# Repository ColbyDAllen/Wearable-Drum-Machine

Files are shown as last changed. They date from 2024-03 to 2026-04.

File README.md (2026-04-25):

# Wearable Drum Machine 

12/15/2024 |

This project is mostly complete. Until I can find a more suitable input/sensory solution, please consider this work on hiatus.

Further information can be found at www.colbydanielallen.com.

4/15/2024 |

This project is still in development. 

On the hardware side, I'm focused on creating more reliable FSR finger sensors.
Weather resistant (magentic charger?) enclosure design is backlogged.

On the circuitry side, I'm designing a custom PCB that incorporates power management, sensor/usb/programmig ports, and an embedded speaker module. 

On the software side there's a number of backlogged tasks. I want to fine-tune / build-out the MIDI looping functionality and create a richer way to sequence these patterns. Variable tempo control in standalone operation (via rotary encoder) is also backlogged.

----

04/01/2024 | Regarding software/code:
Until I've split these up into functional sections, the .ino sketches will build on each other in the following order:
1) FSR Input
2) SMF File Storage
3) MIDI Looper

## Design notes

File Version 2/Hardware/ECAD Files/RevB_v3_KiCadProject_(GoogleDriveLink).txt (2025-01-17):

Link to KiCad Project (A bit messy) via Google Drive:

https://drive.google.com/file/d/1cKTnNXydSSYptlRRjlfMmF5JMNGvhg2D/view?usp=sharing

If missing and you would like to download for personal use, feel free to contact me at:

colbyallen939@u.boisestate.edu

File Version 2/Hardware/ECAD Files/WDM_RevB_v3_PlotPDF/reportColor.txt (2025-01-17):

Plotted to 'C:\Users\Colby\Desktop\Programs\KiCad\WDM_RevB_v3\WDM_RevB_v3\WDM_RevB_v3_PlotPDF\WDM_RevB_v3-Edge_Cuts.pdf'.
Plotted to 'C:\Users\Colby\Desktop\Programs\KiCad\WDM_RevB_v3\WDM_RevB_v3\WDM_RevB_v3_PlotPDF\WDM_RevB_v3-F_Fab.pdf'.
Plotted to 'C:\Users\Colby\Desktop\Programs\KiCad\WDM_RevB_v3\WDM_RevB_v3\WDM_RevB_v3_PlotPDF\WDM_RevB_v3-B_Fab.pdf'.
Info: Done.

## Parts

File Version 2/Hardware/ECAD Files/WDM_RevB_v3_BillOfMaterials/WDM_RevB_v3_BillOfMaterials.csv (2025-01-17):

Id | Designator | Footprint | Quantity | Designation | Supplier and ref
1 | U4 | SO3016_SPA-M | 1 | S25FL512SAGMFIR13_512MBIT
2 | R20,R24,R15,R25,R26,R14,R27,R16,R22,R28,R17,R21,R37,R29,R19,R23,R30 | RES_10K_R0805 | 17 | 10K
3 | J2 | Teensy4.1_Colby(Footprint) | 1 | T4.1
4 | R33,R36,R39,R40,R34,R32,R35,R31,R43 | RES_2.2K_0805 | 9 | 2.2K
5 | U5 | AP7313-18SAG-7 | 1 | AP7313-18SAG-7
6 | C7,C8 | C_100nF_0805 | 2 | 100 nF
7 | TP2 | TestPoint_PAD.03X.05 | 1 | VPCC(TP)
8 | D2 | CHIPLED_0805_NOOUTLINE | 1 | ORANGE
9 | JP1,JP2,JP3 | SolderJumper-2_P1.3mm_Bridged_Pad1.0x1.5mm | 3 | JUMPER-SMT_2_NC_TRACE_SILK
10 | L2 | IND_2012_TDK-L | 1 | 600 OHM, MPZ2012S601AT000
11 | C11,C18,C10,C2,C19 | C_0.1uF_0805_10MGAP | 5 | 0.1 uF
12 | C17,C12,C9,C4,C20 | C_2.2uF_0805-NO | 5 | 2.2 uF
13 | D3,D6 | CHIPLED_0805_NOOUTLINE | 2 | GREEN
14 | SPKR1 | AdafruitStemmaSpeaker_3923 | 1 | ~
15 | EN_1 | XDCR_PEC11R-4215F-S0024 | 1 | PEC11R-4215F-S0024
16 | SW_4,SW_8,SW_5,SW_7,SW_9,SW_3,SW_2,SW_6,SW_1 | PushButton_KMR211_G_LFS_CNK | 9 | KMR211GLFS
17 | C16,C1,C6,C3 | C_10uF_0805-NO | 4 | 10 uF
18 | U3 | W25Q128JVSIQ | 1 | W25Q128JVSIQ
19 | T1 | MMUN2133LT1G_SC59-BEC | 1 | MMUN2133LT1G
20 | J4,J5 | 1X01_BatteryTerminal_HandSolder | 2 | ~
21 | U6 | QFN50P500X500X90-33N | 1 | SGTL5000XNBA3R2
22 | D4,D8,D10 | CHIPLED_0805_NOOUTLINE | 3 | BLUE
23 | J14 | 53398-0271 | 1 | CONN HEADER SMD R/A 2POS 1.25MM
24 | R13 | RES_100K_0805 | 1 | 50K
25 | D9,D7 | CHIPLED_0805_NOOUTLINE | 2 | YELLOW
26 | U7 | MSOP8_0.65MM | 1 | PAM8302AASCR
27 | TP7 | TestPoint_PAD.03X.05 | 1 | +3V3
28 | TP6 | TestPoint_PAD.03X.05 | 1 | SIG(TP)
29 | R41,R38,R42 | RES_100R_R0805 | 3 | 100R
30 | TP5 | TestPoint_PAD.03X.05 | 1 | GND(TP)
31 | D5,D1 | CHIPLED_0805_NOOUTLINE | 2 | RED
32 | J15 | CUI_SJ-3541AS-SMT-TR-67 | 1 | SJ-3541AS-SMT-TR-67
33 | R1,R4 | RES_1.87M_0805 | 2 | 1.87M
34 | C5 | C_100uF_MLCC_C1210 | 1 | 100 uF
35 | J11,J6,J3,J7 | CUI_SJ-3542AS-SMT-TR-67 | 4 | SJ-3542AS-SMT-TR-67
36 | C13 | C_0.15uF_0805 | 1 | 0.15 uF
37 | MIC1 | 1X02_TH_ | 1 | POM-5046P-C3310-R
38 | R2 | RES_340K_0805 | 1 | 340K
39 | R11 | RES_100K_0805 | 1 | 100K
40 | R8,R7,R9,R6 | RES_1K_0805 | 4 | 1K
41 | R12 | RES_1K_0805 | 1 | 3.3K
42 | U1 | TPS61090RSAR_PVQFN-16 | 1 | TPS61090RSAR
43 | C15,C14 | C_1uF_0805 | 2 | 1 uF
44 | R18 | Thermo_15K_0805-NO | 1 | 15K
45 | VR1 | TRIMPOT_BOURNS_TC42_2mm_SMD | 1 | 10K_TC42_Trimpot
46 | L1 | VLS5045EX330M | 1 | 6.8uH, VLS5045EX-6R8M-H
47 | R3,R5 | RES_200K_0805 | 2 | 200K
48 | U2 | MCP73871_QFN20_4MM | 1 | MCP73871
49 | R10 | RES_270K_0805 | 1 | 270K
50 | SW1 | JS202011JAQN | 1 | JS202011JAQN Slide Switch DPDT Surface Mount, Right Angle
51 | TP4 | TestPoint_PAD.03X.05 | 1 | +3v3(TP)

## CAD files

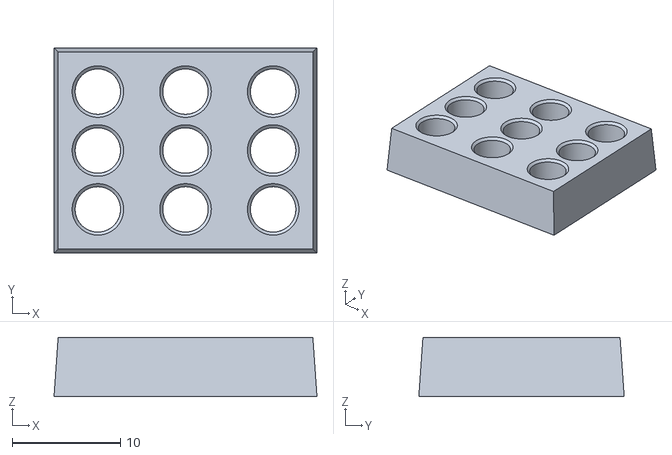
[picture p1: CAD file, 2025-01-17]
Version 2/Hardware/MCAD Files/TestUpload_(Don'tUseUnlessItHelps)/RevB_V3_Assembly - ButtonCasing_WDM(RevB)_Redo4.2-2.STL
24.3 x 19.0 x 5.48

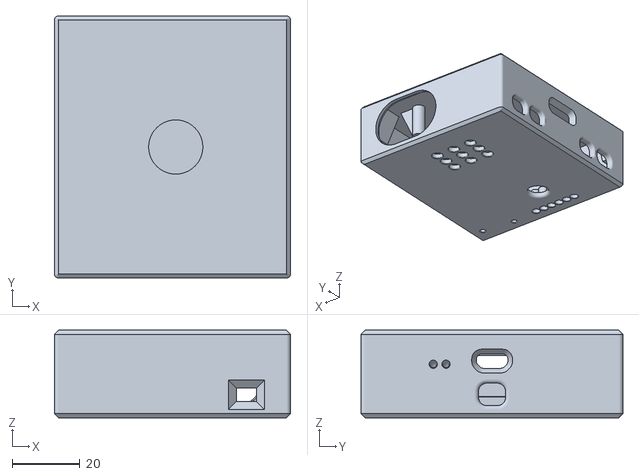
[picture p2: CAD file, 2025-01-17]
Version 2/Hardware/MCAD Files/TestUpload_(Don'tUseUnlessItHelps)/RevB_V3_Assembly - Enclosure_Redo4.3(Backup)-1.STL
69.8 x 77.4 x 25.8

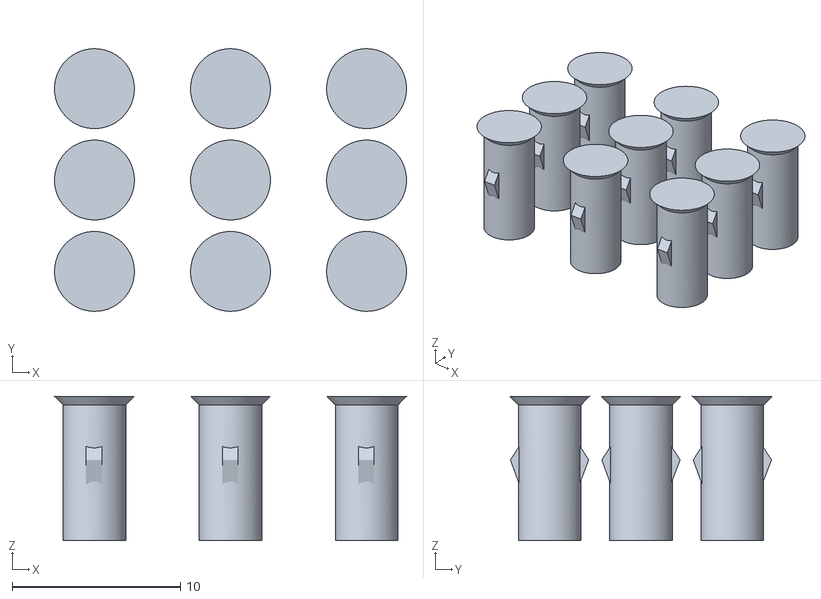
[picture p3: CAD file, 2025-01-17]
Version 2/Hardware/MCAD Files/TestUpload_(Don'tUseUnlessItHelps)/RevB_V3_Assembly - ButtonCaps_Redo4.2-1.STL
20.9 x 15.6 x 8.58

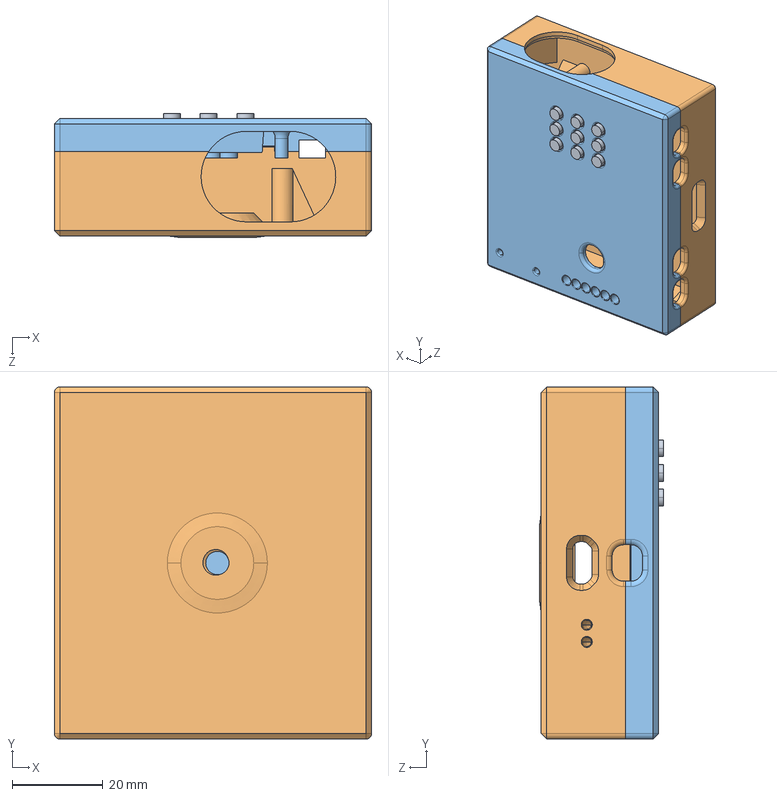
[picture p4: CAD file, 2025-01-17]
Version 2/Hardware/MCAD Files/RevB_V3_Assembly.STEP
69.8 x 77.4 x 27.3 mm

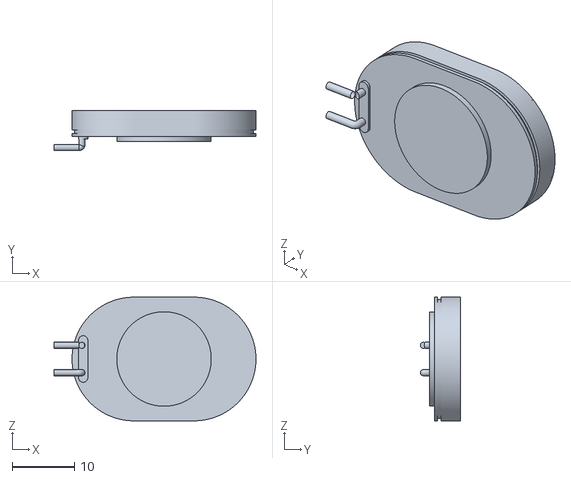
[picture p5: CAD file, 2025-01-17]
Version 2/Hardware/MCAD Files/TestUpload_(Don'tUseUnlessItHelps)/RevB_V3_Assembly - OvalSpeaker_Redo4.2-1.STL
32.5 x 6.50 x 19.9

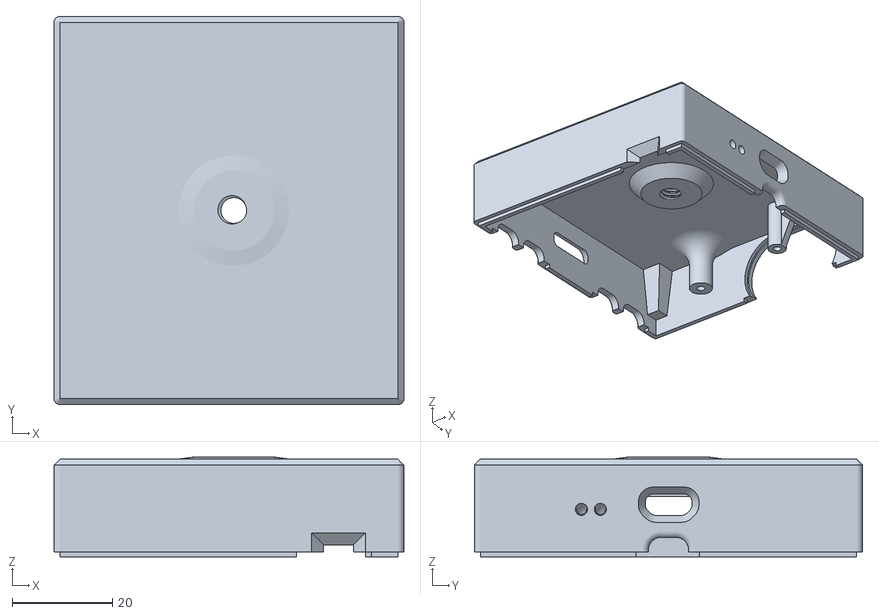
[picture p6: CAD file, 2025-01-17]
Version 2/Hardware/MCAD Files/RevB_V3_BottomEnclosure.STL
69.8 x 77.4 x 19.9

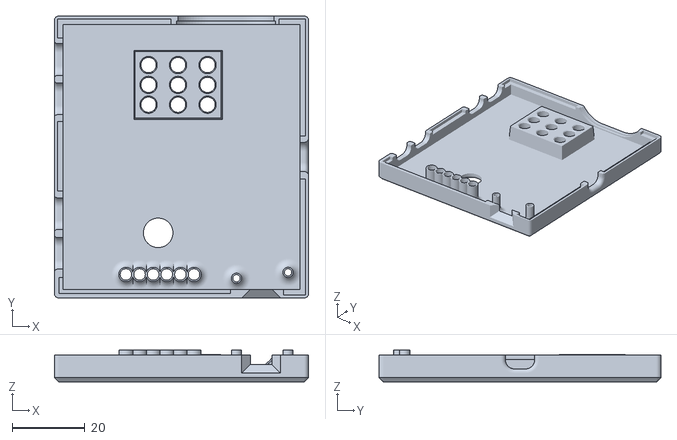
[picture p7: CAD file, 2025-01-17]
Version 2/Hardware/MCAD Files/RevB_V3_TopEnclosure.STL
69.8 x 77.4 x 8.74

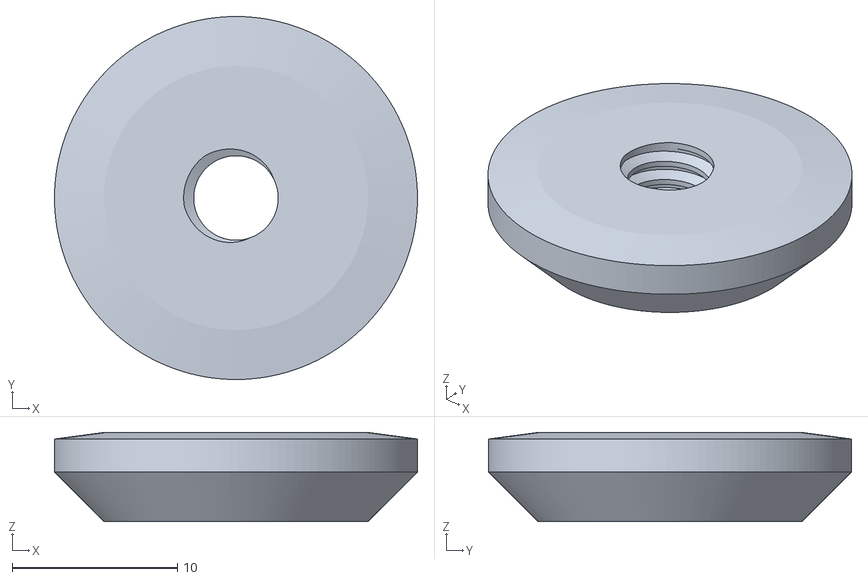
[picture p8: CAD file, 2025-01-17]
Version 2/Hardware/MCAD Files/TestUpload_(Don'tUseUnlessItHelps)/RevB_V3_Assembly - Bolt_Female_WDM(RevB)_Redo4.2-1.STL
22.0 x 22.0 x 5.40

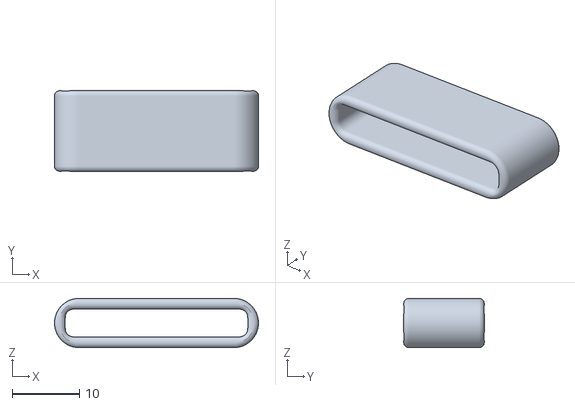
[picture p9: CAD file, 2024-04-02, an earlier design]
Version 1/Hardware/Fusion360/STLs/strap-loop_V1.1.stl
30.4 x 12.0 x 7.33

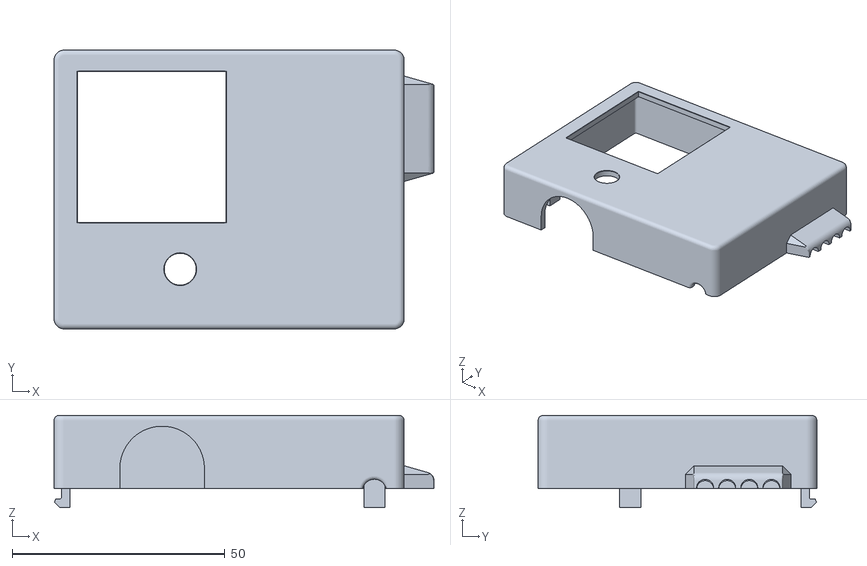
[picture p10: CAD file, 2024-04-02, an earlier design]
Version 1/Hardware/Fusion360/STLs/top-wrist_V1.1.stl
89.4 x 65.6 x 21.7

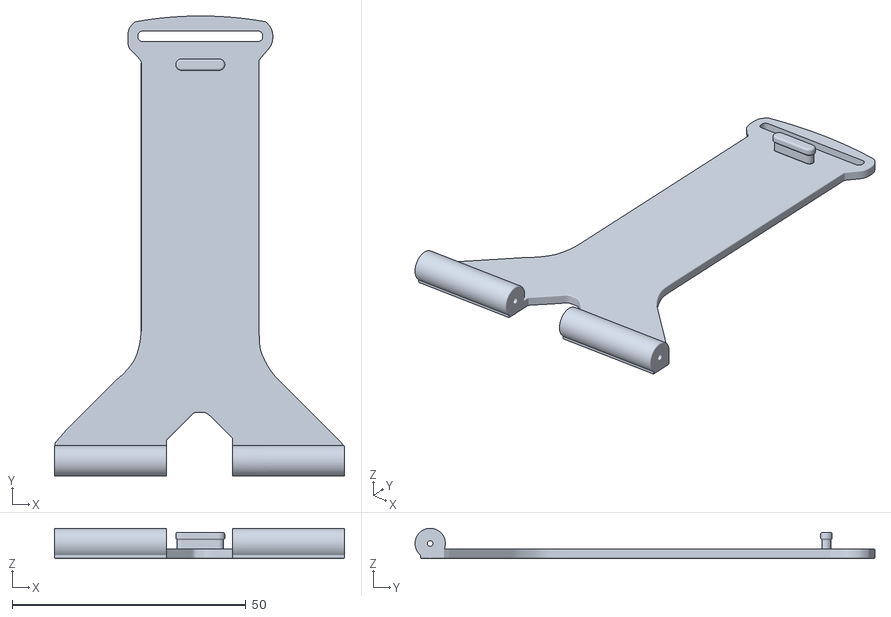
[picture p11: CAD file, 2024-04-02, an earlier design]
Version 1/Hardware/Fusion360/STLs/strap-male_V1.1.stl
62.0 x 98.3 x 6.49

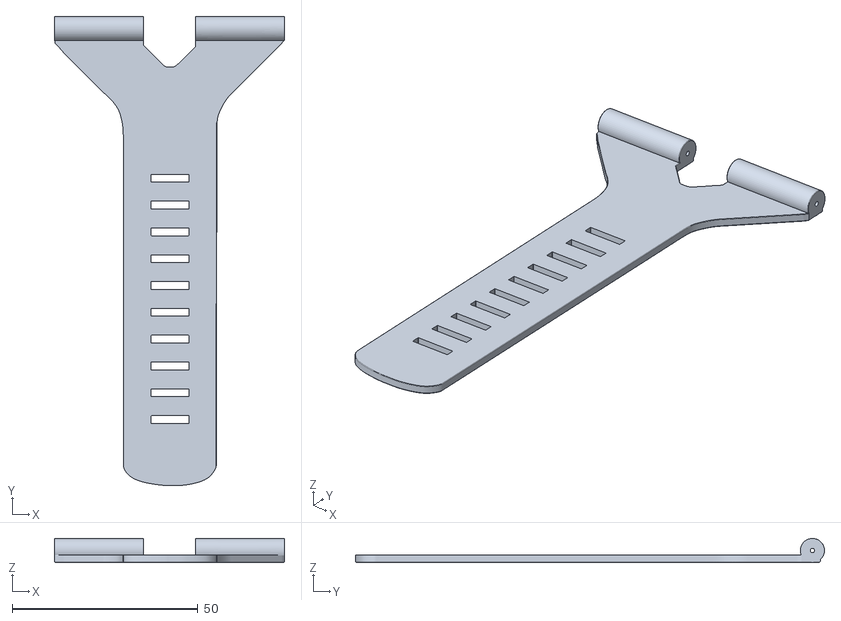
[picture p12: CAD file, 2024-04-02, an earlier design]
Version 1/Hardware/Fusion360/STLs/strap-female_V1.1.stl
62.0 x 126.3 x 6.49

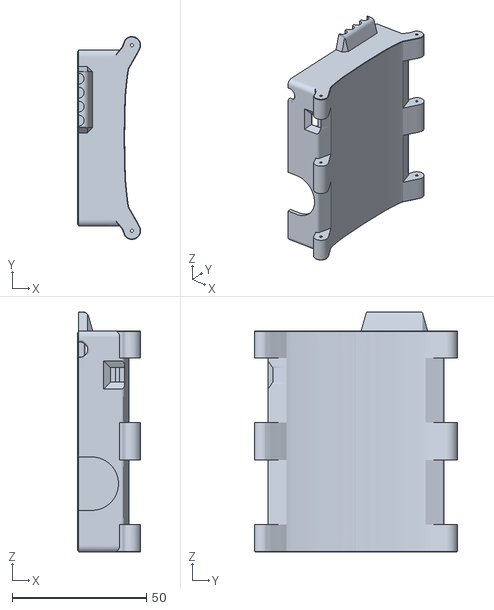
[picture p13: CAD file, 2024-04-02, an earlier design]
Version 1/Hardware/Fusion360/STLs/bottom-wrist_V1.1.stl
23.7 x 75.6 x 89.4

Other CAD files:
Version 2/Hardware/MCAD Files/RevB_V3_ButtonActuators.STL

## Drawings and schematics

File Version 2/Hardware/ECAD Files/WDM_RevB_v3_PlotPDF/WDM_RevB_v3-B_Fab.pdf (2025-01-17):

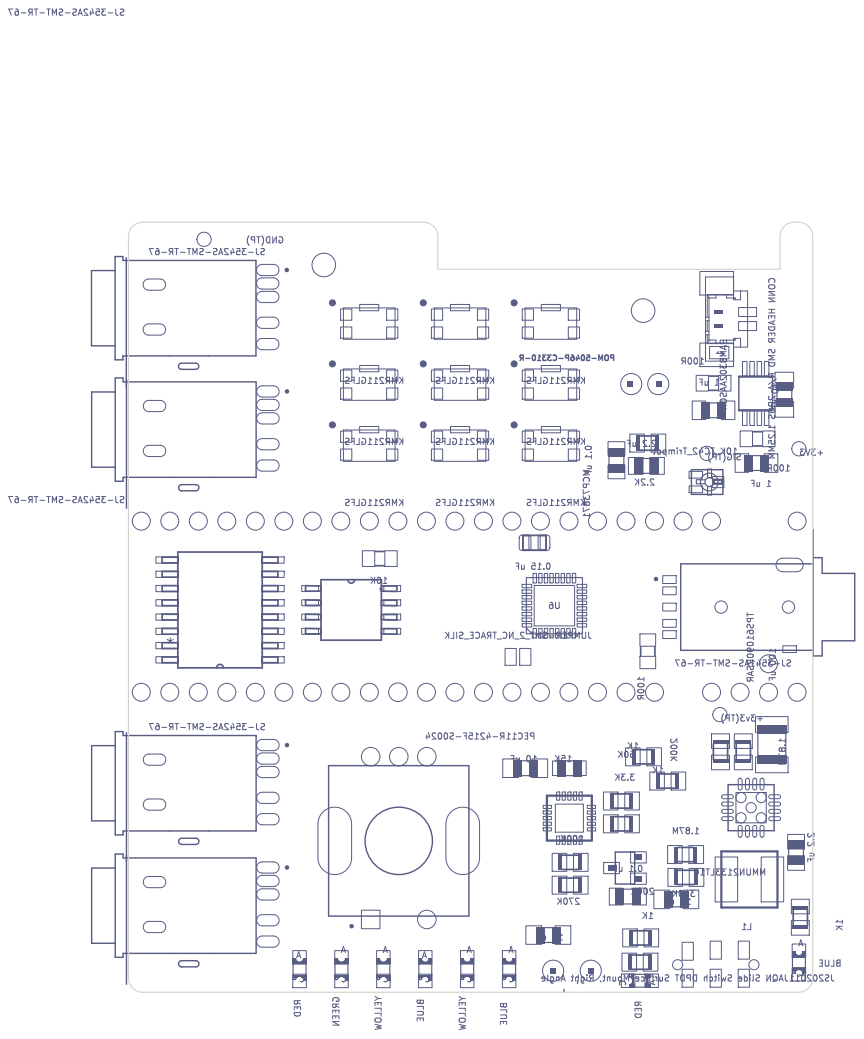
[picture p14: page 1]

SJ-3542AS-SMT-TR-67 0.1 uF

AC CONN HEADER SMD R/A 2POS 1.25MM

200K MCP73871 uF 1 SJ-3542AS-SMT-TR-67

Angle Right Mount, Surface DPDT Switch Slide JS202011JAQN 200K

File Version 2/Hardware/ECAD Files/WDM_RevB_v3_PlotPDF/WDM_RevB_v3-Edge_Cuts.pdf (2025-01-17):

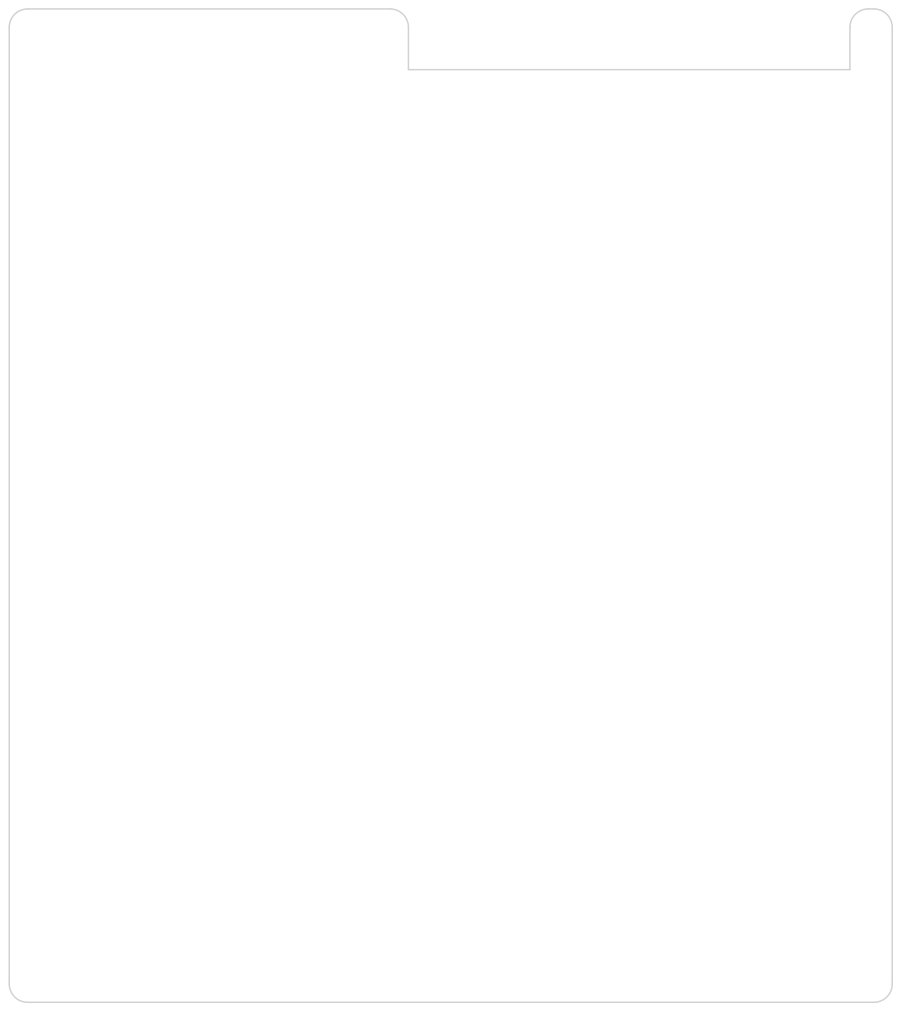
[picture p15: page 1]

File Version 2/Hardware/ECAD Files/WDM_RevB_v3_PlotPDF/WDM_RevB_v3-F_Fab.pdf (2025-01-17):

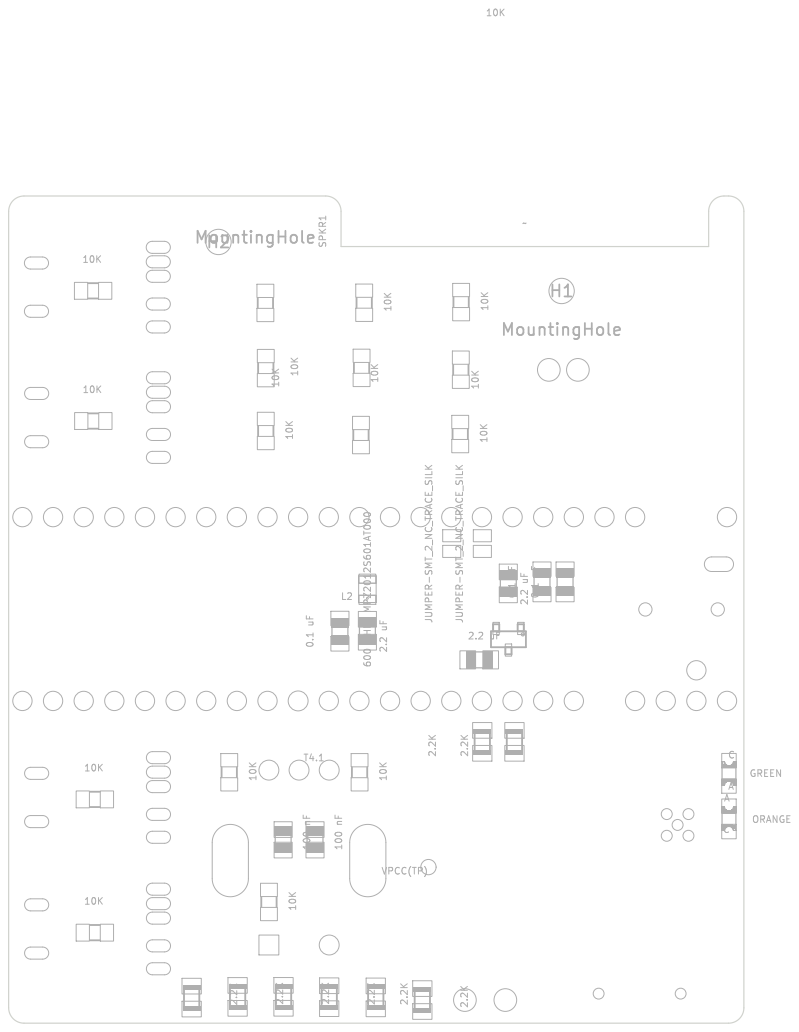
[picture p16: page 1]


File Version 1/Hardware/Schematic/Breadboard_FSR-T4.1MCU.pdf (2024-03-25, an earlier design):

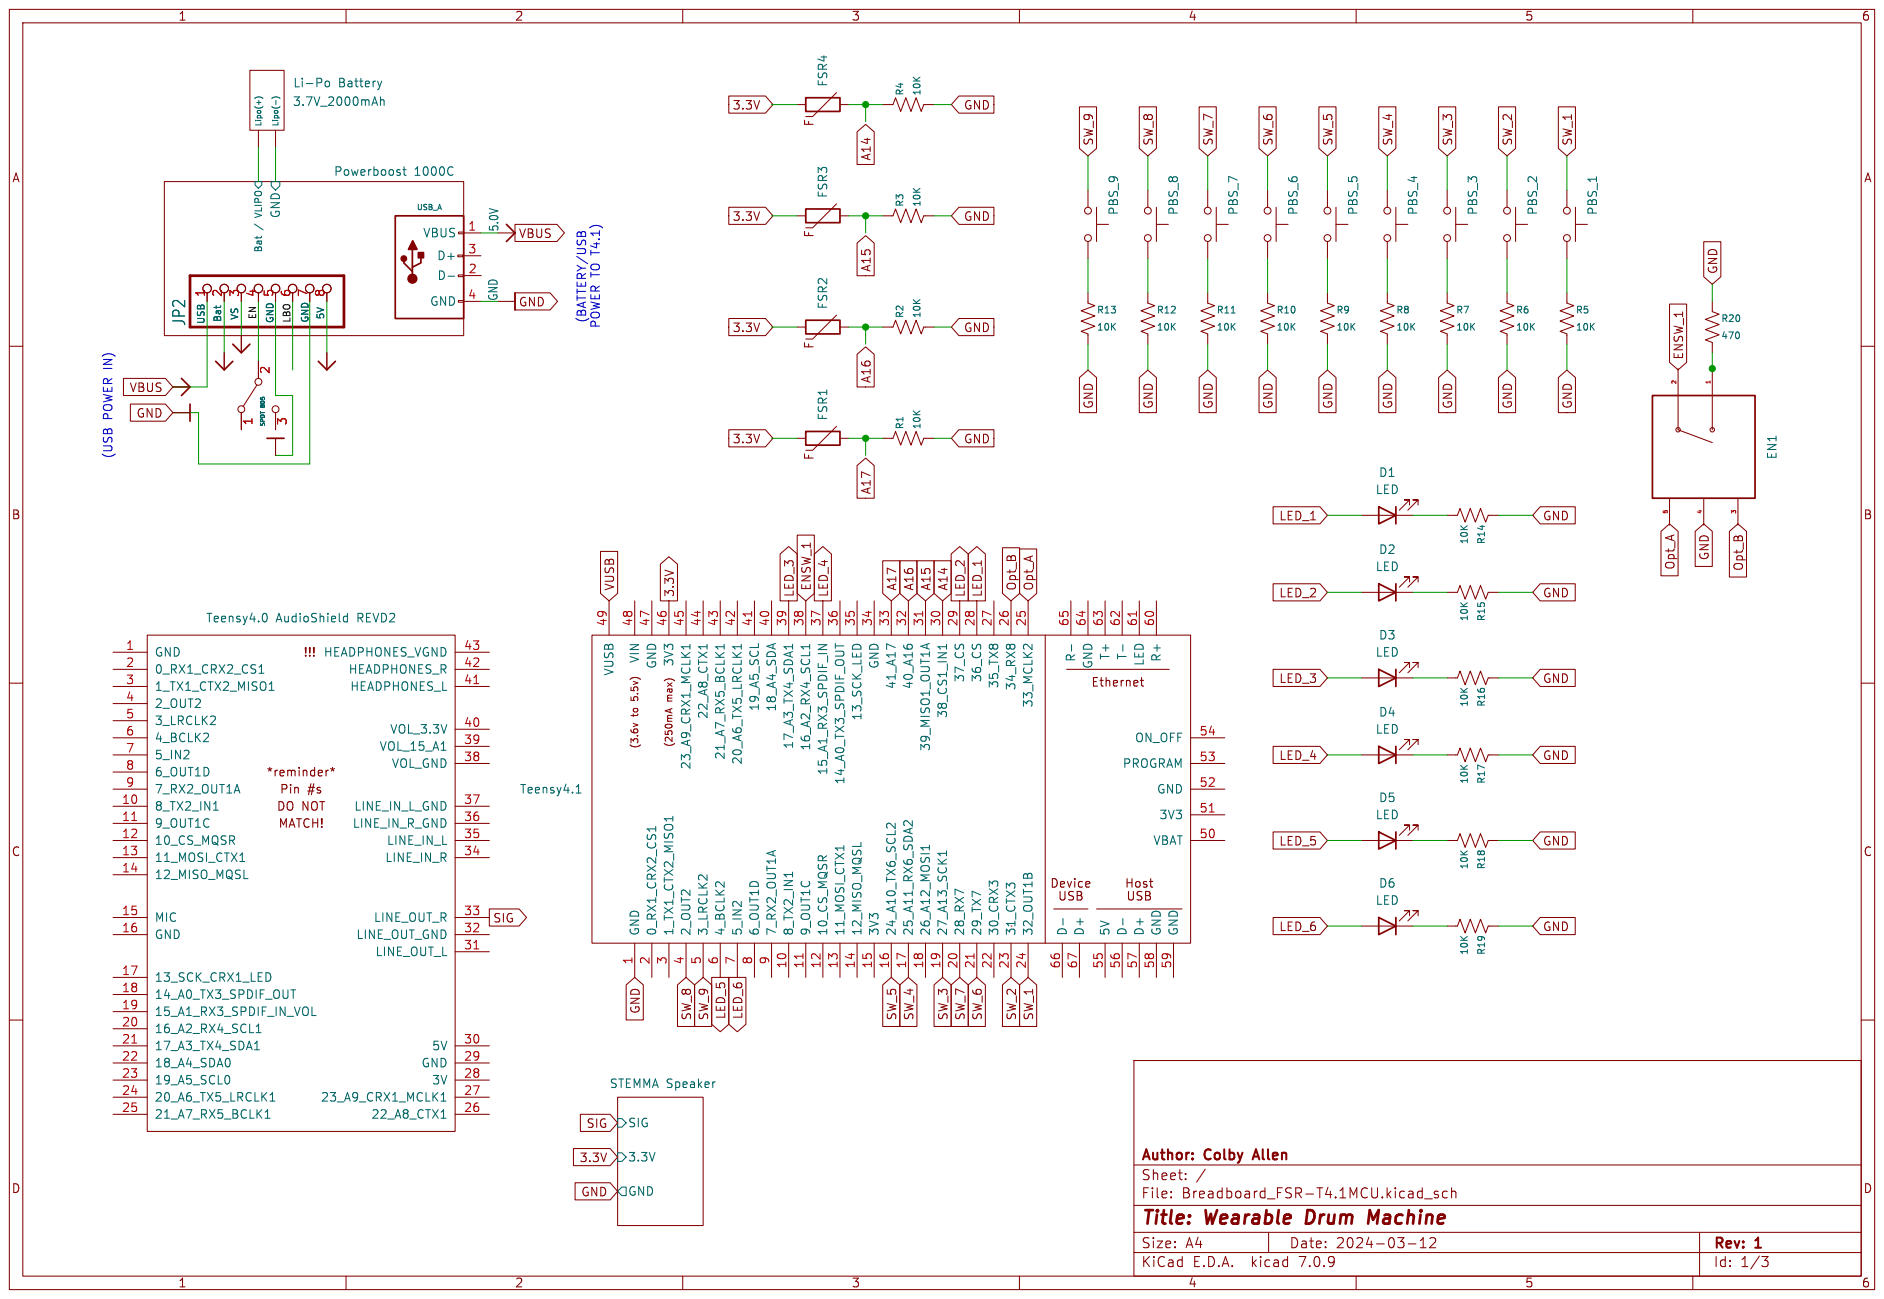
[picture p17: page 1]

2 SPDT 3 805 PBS_7 Bat GND PBS_5 USB Lipo(+) Lipo(-)3.7V_2000mAh

STEMMA Speaker Bat / VLIPO GND

8 USB Bat GND SPDT 805 1

File: Breadboard_FSR-T4.1MCU.kicad_sch Sheet: / Author: Colby Allen

Id: 1/3 Title: Wearable Drum Machine

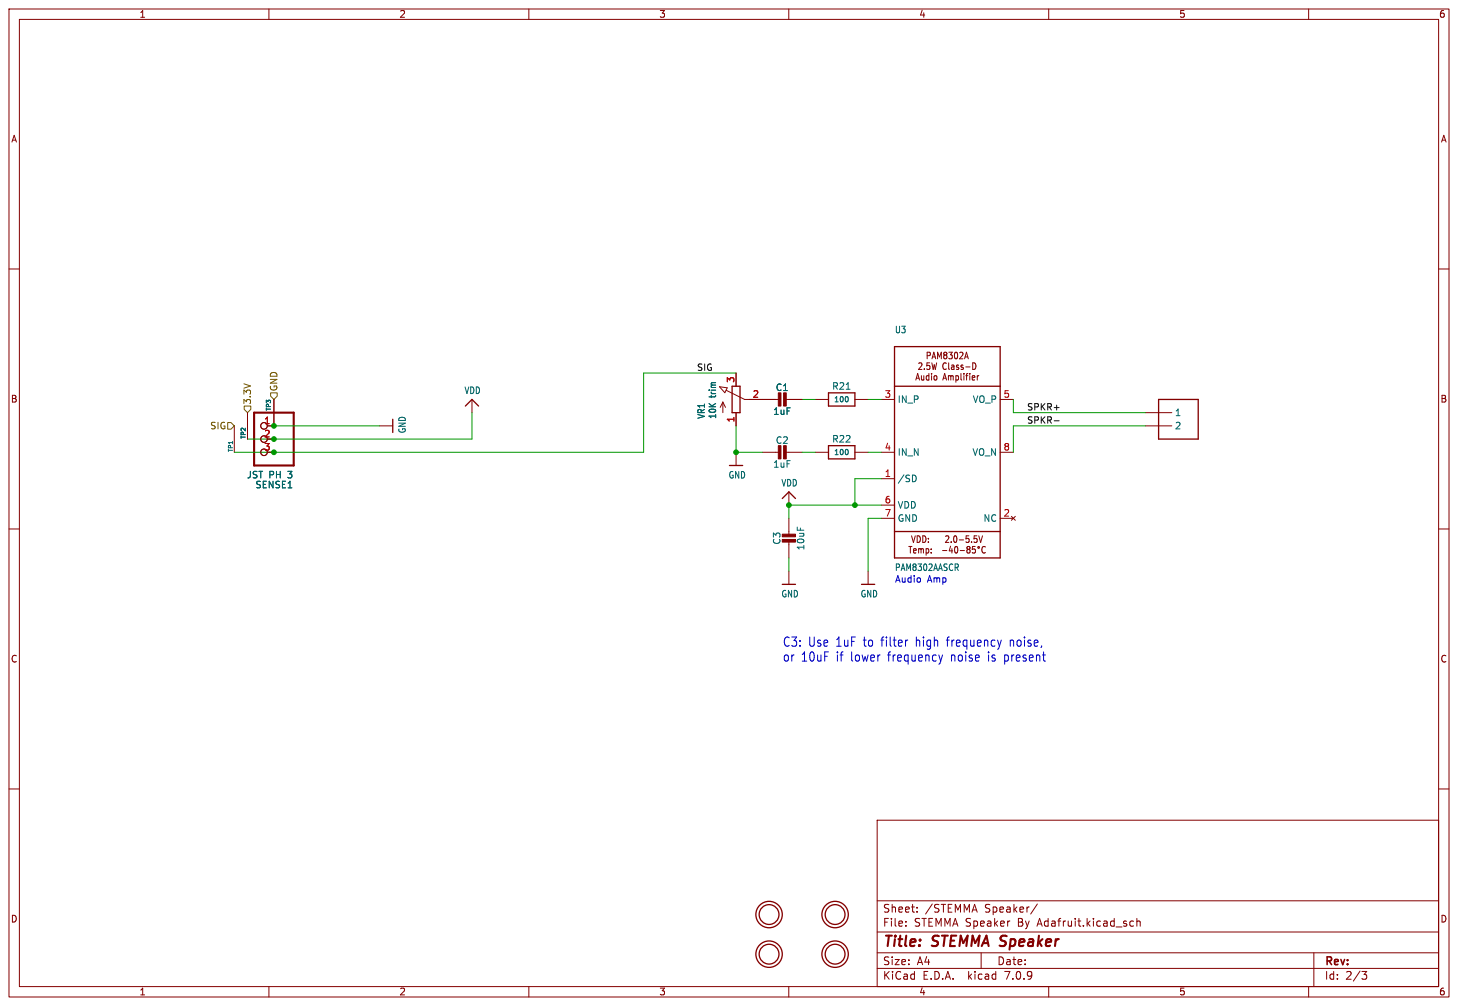
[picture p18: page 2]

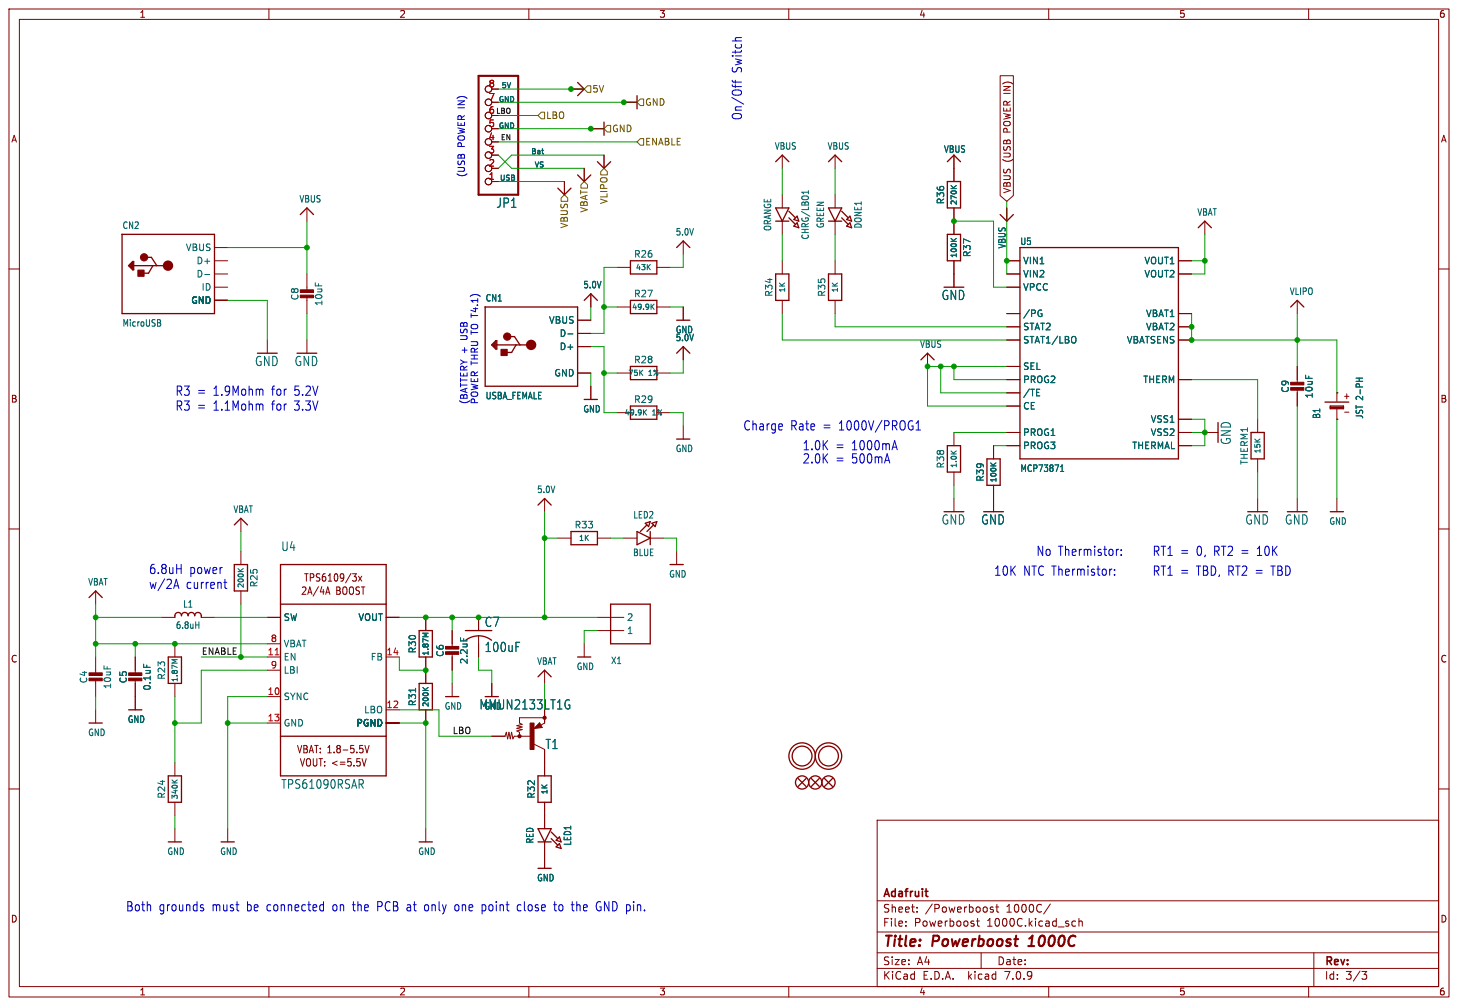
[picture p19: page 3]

10K NTC Thermistor: (BATTERY + USB POWER THRU TO T4.1)

Both grounds must be connected on the PCB at only one point close to the GND pin.

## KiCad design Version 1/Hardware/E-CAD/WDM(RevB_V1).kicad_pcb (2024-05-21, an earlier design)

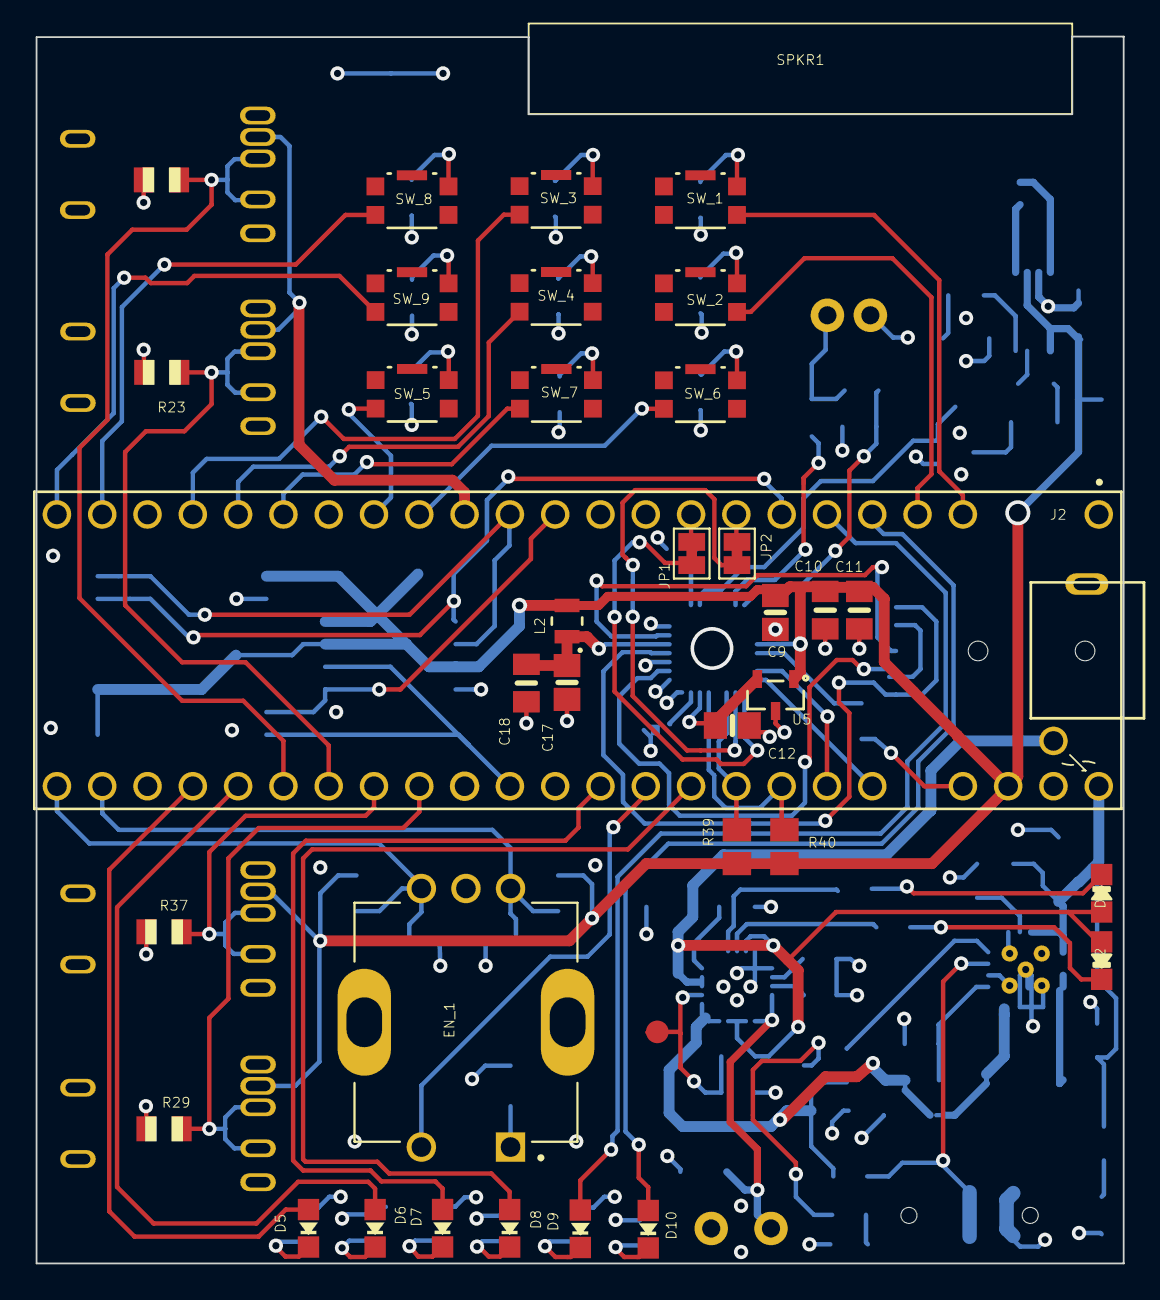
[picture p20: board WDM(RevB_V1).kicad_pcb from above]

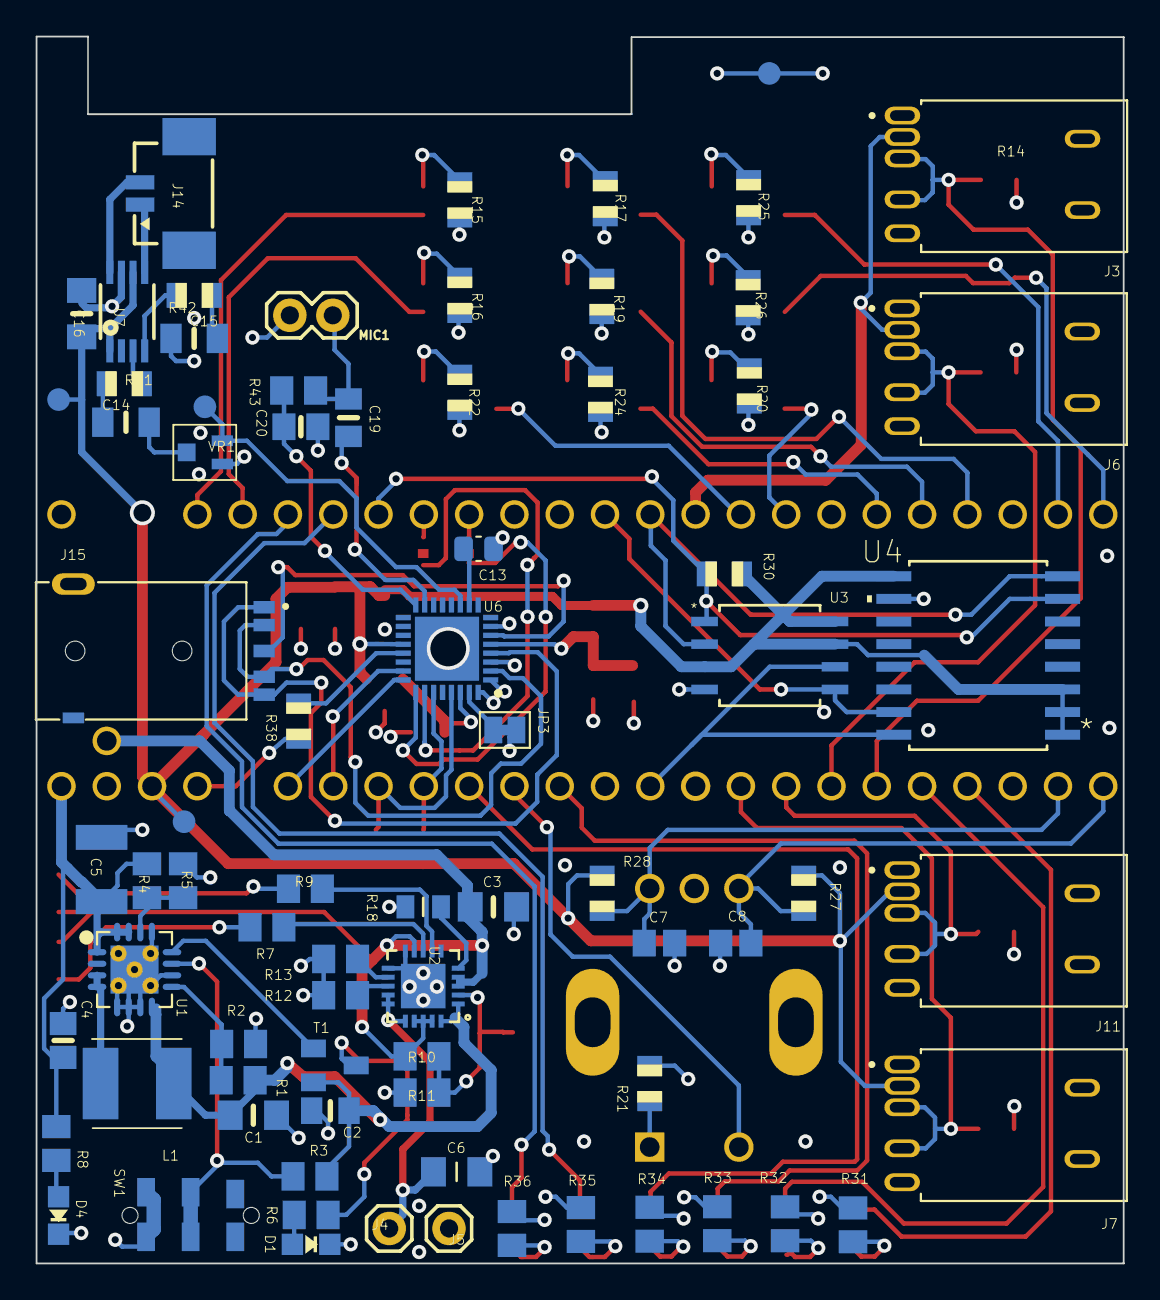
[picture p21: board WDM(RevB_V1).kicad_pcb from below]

Board: 4 copper layers, 61.0 x 68.8 mm, 114 parts (77 on the bottom side), 92 nets.

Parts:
C1, C3, C6, C16: 10 uF; C_10uF_0805-NO
C2, C10, C11, C18, C19: 0.1 uF; C_0.1uF_0805_10MGAP
C4, C9, C12, C17, C20: 2.2 uF; C_2.2uF_0805-NO
C5: 100 uF; C_100uF_MLCC_C1210
C7, C8: 100 nF; C_100nF_0805
C13: 0.15 uF; C_0.15uF_0805
C14, C15: 1 uF; C_1uF_0805
D1, D5: RED; CHIPLED_0805_NOOUTLINE
D2: ORANGE; CHIPLED_0805_NOOUTLINE
D3, D6: GREEN; CHIPLED_0805_NOOUTLINE
D4, D8, D10: BLUE; CHIPLED_0805_NOOUTLINE
D7, D9: YELLOW; CHIPLED_0805_NOOUTLINE
EN_1: PEC11R-4215F-S0024; XDCR_PEC11R-4215F-S0024
J2: T4.1; Teensy4.1_Colby(Footprint)
J3, J6, J7, J11: SJ-3542AS-SMT-TR-67; CUI_SJ-3542AS-SMT-TR-67
J4, J5: 1X01_BatteryTerminal_HandSolder
J14: CONN HEADER SMD R/A 2POS 1.25MM; 53398-0271
J15: SJ-3541AS-SMT-TR-67; CUI_SJ-3541AS-SMT-TR-67
JP1, JP2, JP3: JUMPER-SMT_2_NC_TRACE_SILK; SolderJumper-2_P1.3mm_Bridged_Pad1.0x1.5mm
L1: 6.8uH, VLS5045EX-6R8M-H; VLS5045EX330M
L2: 600 OHM, MPZ2012S601AT000; IND_2012_TDK-L
MIC1: POM-5046P-C3310-R; 1X02_TH_
R1, R4: 1.87M; RES_1.87M_0805
R2: 340K; RES_340K_0805
R3, R5: 200K; RES_200K_0805
R6, R7, R8, R9, R12: 1K; RES_1K_0805
R10: 270K; RES_270K_0805
R11, R13: 100K; RES_100K_0805
R14, R15, R16, R17, R19, R20, R21, R22, R23, R24, R25, R26, R27, R28, R29, R30, R37: 10K; RES_10K_R0805
R18: 15K; Thermo_15K_0805-NO
R31, R32, R33, R34, R35, R36, R39, R40, R43: 2.2K; RES_2.2K_0805
R38, R41, R42: 100R; RES_100R_R0805
SPKR1: AdafruitStemmaSpeaker_3923
SW1: JS202011JAQN Slide Switch DPDT Surface Mount, Rig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; JS202011JAQN
SW_1, SW_2, SW_3, SW_4, SW_5, SW_6, SW_7, SW_8, SW_9: KMR211GLFS; PushButton_KMR211_G_LFS_CNK
T1: MMUN2133LT1G; MMUN2133LT1G_SC59-BEC
TP2: VPCC(TP); TestPoint_PAD.03X.05
TP4: +3v3(TP); TestPoint_PAD.03X.05
TP5: GND(TP); TestPoint_PAD.03X.05
TP6: SIG(TP); TestPoint_PAD.03X.05
TP7: +3V3; TestPoint_PAD.03X.05
U1: TPS61090RSAR; TPS61090RSAR_PVQFN-16
U2: MCP73871; MCP73871_QFN20_4MM
U3: W25Q128JVSIQ
U4: S25FL512SAGMFIR13_512MBIT; SO3016_SPA-M
U5: AP7313-18SAG-7
U6: SGTL5000XNBA3R2; QFN50P500X500X90-33N
U7: PAM8302AASCR; MSOP8_0.65MM
VR1: 10K_TC42_Trimpot; TRIMPOT_BOURNS_TC42_2mm_SMD

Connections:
+1V8: C12.1, U5.2 (OUT), U6.30 (VDDD)
+3V3: C9.1, C10.1, C11.1, C16.1, J2.T3.3V (3.3V), J3.3, J6.3, J7.3, J11.3, L2.2, R27.1, R28.1, R30.2, R39.2, R40.2, TP4.P$1 (1), TP7.P$1 (1), U3.3 (~WP(IO2)), U3.7 (~HOLD(IO3)), U3.8 (VCC), U4.1 (~HOLD/IO3), U4.2 (VCC), U4.3 (~RESET/RFU), U4.9 (~WP/IO2), U5.1 (IN), U6.20 (VDDIO), U7.1 (/SD), U7.6 (VDD)
+5V: C4.1, C5.1, J2.+5V (VIN), R4.1, R8.1, U1.1 (VOUT), U1.15 (VOUT), U1.16 (VOUT)
/ FSRpin_1_A14: J2.38 (38_CS1_IN1), J3.2, J3.5, R14.1
/ FSRpin_2_A15: J2.39 (39_MISO1_OUT1A), J6.2, J6.5, R23.1
/ FSRpin_3_A16: J2.40 (40_A16), J11.2, J11.5, R37.1
/ FSRpin_4_A17: J2.41 (41_A17), J7.2, J7.5, R29.1
/ECHOPin: J2.24 (24_A10_TX6_SCL2), SW_6.3
/ENABLE: R3.2, SW1.2, SW1.5, U1.11 (EN)
/LBO: T1.B, U1.12 (LBO)
/PLAYledPin: D6.A, J2.37 (37_CS)
/Pin6: J2.6 (6_OUT1D), R30.1, U3.1 (~CS), U4.7 (~CS)
/Pin7: J2.7 (7_RX2_OUT1A), JP2.1
/Pin8: J2.8 (8_TX2_IN1), JP1.1
/Pin11: J2.11 (11_MOSI_CTX1), U3.5 (DI(IO0)), U4.15 (SI/IO0)
/Pin12: J2.12 (12_MISO_MQSL), U3.2 (DO(IO1)), U4.8 (SO/IO1)
/Pin13: J2.13 (13_SCK_LED), U3.6 (CLK), U4.16 (SCK)
/Pin20: J2.20 (20_A6_TX5_LRCLK1), U6.23 (I2S_LRCLK)
/Pin21: J2.21 (21_A7_RX5_BCLK1), U6.24 (I2S_SCLK)
/Pin23: J2.23 (23_A9_CRX1_MCLK1), R38.1
/RECPin: J2.32 (32_OUT1B), SW_9.3
/SCL: J2.19 (19_A5_SCL), R40.1, U6.29 (CTRL_CLK)
/SDA: J2.18 (18_A4_SDA), R39.1, U6.27 (CTRL_DATA)
/SPKR+: J14.1, U7.5 (VO_P)
/SPKR-: J14.2, U7.8 (VO_N)
/Sig: TP6.P$1 (1), U6.11 (LINEOUT_R), VR1.3 (E)
/VDDA: C17.1, C18.1, L2.1, U6.5 (VDDA)
/VPCC(TP): R10.2, R11.1, TP2.P$1 (1), U2.P$2 (VPCC)
/clockTrigPin: J2.27 (27_A13_SCK1), SW_7.3
/optAPin: C7.2, EN_1.A, J2.34 (34_RX8), R28.2
/optBPin: C8.2, EN_1.B, J2.33 (33_MCLK2), R27.2
/pushRotaryPin: EN_1.2, J2.16 (16_A2_RX4_SCL1)
/startPin: J2.31 (31_CTX3), SW_8.3
/trackLEDPin_1: D7.A, J2.15 (15_A1_RX3_SPDIF_IN)
/trackLEDPin_2: D8.A, J2.17 (17_A3_TX4_SDA1)
/trackLEDPin_3: D9.A, J2.5 (5_IN2)
/trackLEDPin_4: D10.A, J2.4 (4_BCLK2)
/trackPin_1: J2.28 (28_RX7), SW_4.3
/trackPin_2: J2.29 (29_TX7), SW_3.3
/trackPin_3: J2.3 (3_LRCLK2), SW_2.2
/trackPin_4: J2.2 (2_OUT2), SW_1.2
/undoPin: J2.25 (25_A11_RX6_SDA2), SW_5.3
/ RECLEDPin: D5.A, J2.36 (36_CS)
GND: C1.2, C2.2, C3.1, C4.2, C5.2, C6.2, C7.1, C8.1, C9.2, C10.2, C11.2, C12.2, C13.2, C15.2, C16.2, C17.2, C18.2, C20.2, D1.C, D4.C, EN_1.C, J2.GND_0, J2.GND_1, J2.GND_2, J3.1, J3.4, J5.1, J6.1, J6.4, J7.1, J7.4, J11.1, J11.4, JP3.1, MIC1.2, R2.2, R5.2, R11.2, R12.2, R13.2, R14.2, R15.1, R16.1, R17.1, R18.2, R19.1, R20.1, R21.2, R22.1, R23.2, R24.1, R25.1, R26.1, R29.2, R31.2, R32.2, R33.2, R34.2, R35.2, R36.2, R37.2, SW1.3, SW1.6, TP5.P$1 (1), U1.5 (PGND), U1.6 (PGND), U1.7 (PGND), U1.10 (SYNC), U1.13 (GND), U1.P$18 (PAD), U1.P$19 (PAD), U1.P$20 (PAD), U1.P$21 (PAD), U1.P$22 (PAD), U1.THERMAL (PAD), U2.P$10 (VSS1), U2.P$11 (VSS2), U2.P$21 (EP), U3.4 (GND), U4.10 (VSS), U5.3 (GND), U6.1 (GND_1), U6.3 (GND_2), U6.7 (AGND), U6.32 (CTRL_MODE), U6.33 (GND_3), U7.7 (GND), VR1.1 (A)
unnamed: C14.1, R41.1
unnamed: C15.1, R42.1
unnamed: C19.2, MIC1.1, R43.2
unnamed: D1.A, R6.2
unnamed: D2.C, R7.1
unnamed: D3.C, R9.1
unnamed: D4.A, R8.2
unnamed: D5.C, R31.1
unnamed: D6.C, R32.1
unnamed: D7.C, R33.1
unnamed: D8.C, R34.1
unnamed: D9.C, R35.1
unnamed: D10.C, R36.1
unnamed: EN_1.1, R21.1
unnamed: L1.2, U1.3 (SW), U1.4 (SW)
unnamed: R6.1, T1.C
unnamed: R15.2, SW_1.1
unnamed: R16.2, SW_2.1
unnamed: R17.2, SW_3.1
unnamed: R19.2, SW_4.1
unnamed: R20.2, SW_5.1
unnamed: R22.2, SW_6.1
unnamed: R24.2, SW_7.1
unnamed: R25.2, SW_8.1
unnamed: R26.2, SW_9.1
unnamed: R4.2, R5.1, U1.14 (FB)
unnamed: R1.2, R2.1, U1.9 (LBI)
unnamed: R12.1, U2.P$13 (PROG1)
unnamed: R13.1, U2.P$12 (PROG3)
unnamed: R7.2, U2.P$8 (STAT1/LBO)
unnamed: R9.2, U2.P$7 (STAT2)
unnamed: R18.1, U2.P$5 (THERM)
unnamed: JP3.2, U6.31 (CTRL_ADR0_CS)
unnamed: J15.3, U6.6 (HP_L)
unnamed: J15.2, J15.5, U6.2 (HP_R)
unnamed: J15.1, J15.4, U6.4 (HP_VGND)
unnamed: JP2.2, U6.26 (I2S_DIN)
unnamed: JP1.2, U6.25 (I2S_DOUT)
unnamed: C19.1, U6.15 (MIC)
unnamed: C20.1, R43.1, U6.16 (MIC_BIAS)
unnamed: R38.2, U6.21 (SYS_MCLK)
unnamed: C13.1, U6.10 (VAG)
unnamed: R42.2, U7.4 (IN_N)
unnamed: R41.2, U7.3 (IN_P)
unnamed: C14.2, VR1.2 (S)
VBUS: C3.2, D2.A, D3.A, J2.49 (VUSB), R10.1, U2.P$3 (SEL), U2.P$4 (PROG2), U2.P$9 (/TE), U2.P$17 (CE), U2.P$18 (VIN1), U2.P$19 (VIN2)
VLIPO: C6.1, J4.1, U2.P$14 (VBAT1), U2.P$15 (VBAT2), U2.P$16 (VBATSENS)
V_Batt: C1.1, C2.1, L1.1, R1.1, R3.1, T1.E, U1.8 (VBAT), U2.P$1 (VOUT1), U2.P$20 (VOUT2)

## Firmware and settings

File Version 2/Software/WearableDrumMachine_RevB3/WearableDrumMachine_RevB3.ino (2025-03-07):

// main.cpp or main.ino

#include "Globals.h"
#include "AudioSystem.h"
#include "MIDIHandler.h"
#include "FSRHandler.h"
#include "SequencerHandler.h"
#include "SdBrowse.h"
#include "LoopedNoteFunctions.h"
#include "MIDIFileWriter.h"
extern MIDIFileWriter midiFileWriter;

#include "AudioSampleKickkhronos.h" 
#include "AudioSampleHh1khronos.h" 
#include "AudioSampleSnarekhronos.h" 
#include "AudioSampleHh2khronos.h" 
#include <Bounce.h> 
#include <Audio.h> 
#include <Wire.h> 
#include <SPI.h> 
#include <SD.h> 
#include <MIDI.h> 
#include <SerialFlash.h> 
#include <ResponsiveAnalogRead.h> 
#include <RTClib.h> 

AudioSystem audioSys; 
MIDIHandler midiHandler; 
FSRHandler fsrHandler;
SequencerHandler sequencerHandler;
MIDIFileWriter midiFileWriter;
SDBrowse sdBrowse;

void setup() {
  Serial.begin(115200);
  delay(1200);
  Serial.println("Booting FULL Wearable Drum + SerialFlash approach...");

  audioSys.initAudioSystem();

  // Pin Assignments
  pinMode(RECPin, INPUT_PULLUP); 
  pinMode(startPin, INPUT_PULLUP); 
  pinMode(pushRotaryPin, INPUT_PULLUP); 
  pinMode(optAPin, INPUT_PULLUP); 
  pinMode(optBPin, INPUT_PULLUP); 
  pinMode(sampleBrowsePin, INPUT_PULLUP); 
  pinMode(undoPin, INPUT_PULLUP); 
  pinMode(clockTrigPin, INPUT_PULLUP); 
  for (int i=0; i<MAX_TRACKS; i++) { 
    pinMode(trackPin[i], INPUT_PULLUP); 
  } 
  pinMode(RECLEDPin, OUTPUT); 
  pinMode(PLAYledPin, OUTPUT); 
  for(int j=0; j<MAX_TRACKS; j++) { 
    pinMode(trackLEDPin[j], OUTPUT); // TODO disable all unsused pins to save power 
  } 
  pinMode(PLACE_MARKER_PIN, INPUT); 

  midiHandler.initMIDI();

  // If RTC: 
  /* 
    if(RTC.begin()) { 
      SdFile::dateTimeCallback(dateTime); 
      HAS_RTC = true;
  } 
  */ 

  // Initialize microSD card 
  if(!SD.begin(BUILTIN_SDCARD)) { 
    Serial.println("SD.begin(BUILTIN_SDCARD) fail!"); 
  } else { 
    Serial.println("SD OK. "); 
  } 

  // Initialize SerialFlash on pin 6 
  if(!SerialFlash.begin(6)) { 
    Serial.println("SerialFlash.begin(6) FAIL or chip not detected!"); 
  } else { 
    Serial.println("SerialFlash is ready on pin 6. (Ensure EraseEverything done.)"); 
  } 

  // Initialize file writing 
  midiFileWriter.creatNextFile(); 
  if(file) { 
    midiFileWriter.writeMidiPreamble(); 
  } 

  fsrHandler.initFSRs(); // sets up each FSR with ResponsiveAnalogRead (among other things)
}

void loop() {

  // Read MIDI activity
  midiHandler.updateMIDI(); 
  
  #ifdef SEND_INT_CLOCK
    SendClock();
    //sequencer.SendClock(); 
  #endif

  // Update sequencer logic
  sequencerHandler.update(); // this calls if(PLAY){SequenceNotes();...}

  // Sample browsing
  sdBrowse.sampleBrowse();
  clockTrigSwitch();

  // FSR scanning
  fsrHandler.updateFSRs(); // scans them repeatedly

  midiFileWriter.checkForMarker();
  midiFileWriter.updateFile();

  sdBrowse.updatePreview();
}

//===================================================================
// SendClock, myNoteOnLooped, myNoteOffLooped
//===================================================================
void SendClock(){
  if(incomingClock!=1){
    if(micros()-clockTime>=clockLenght){
      clockTime=micros();
      usbMIDI.sendRealTime(usbMIDI.Clock);
    }
  }
}

void myNoteOnLooped(byte channel, byte note, byte velocity){
  int delta = midiFileWriter.getDelta(); //NEW
  midiFileWriter.writeToFile(NOTE_ON_EVENT, note, velocity, delta);
}

void myNoteOffLooped(byte channel, byte note, byte velocity){
  int delta = midiFileWriter.getDelta(); //NEW
  midiFileWriter.writeToFile(NOTE_OFF_EVENT, note, velocity, delta);
}




void Handle_Clock(){
  if(incomingClock<2){
    if(incomingClock==1){
      usbMIDI.sendRealTime(MIDI_NAMESPACE::Clock);
    }
    clockTick++;
    if(clockTick==1){
      firstClockTick=micros();
    } else if(clockTick>24){
      clockTick=0;
      incomingClock=1;
      beatLenght=micros()-firstClockTick;
      if(beatLenght!=prevBeatLenght && !waitingFirstSeq){
        //Compute_Note_Times();
        prevBeatLenght=beatLenght;
      }
    }
  }
}

void Compute_Note_Times(){
  double multiplier=(double)beatLenght/(double)prevBeatLenght;
  loopLenght= (unsigned long)(loopLenght*multiplier);
  for(int i=0;i<MAX_NOTES;i++){
    for(int j=0;j<MAX_SEQUENCES;j++){
      if(noteTime[i][j]<4294967295){
        noteTime[i][j]= (unsigned long)(noteTime[i][j]*multiplier);
      }
    }
  }
}

void clockTrigSwitch(){
  if(digitalRead(clockTrigPin)!=clockTrigState){
    clockTrigState=!clockTrigState;
    if(clockTrigState==HIGH){
      trigCount++;
      if(trigCount==1){
        firstTrigTick=micros();
      } else if(trigCount>1){
        trigCount=0;
        incomingClock=2;
        beatLenght=micros()-firstTrigTick;
        if(beatLenght!=prevBeatLenght && !waitingFirstSeq){
          //Compute_Note_Times();
          prevBeatLenght=beatLenght;
        }
      }
    }
  }
}

//===================================================================
// dateTime for optional RTC
//===================================================================
void dateTime(uint16_t* date, uint16_t* time){
  DateTime d = RTC.now();
  *date = FAT_DATE(d.year(), d.month(), d.day());
  *time = FAT_TIME(d.hour(), d.minute(), d.second());
}

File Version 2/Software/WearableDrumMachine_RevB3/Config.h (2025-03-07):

// Config.h
// Forcompile-time constants (the #defines and const byte pin definitions)
// Typically, Config.h or “configuration” headers hold macros (#define) or const declarations that never change at run time. They are set in stone at compile time.

#ifndef CONFIG_H
#define CONFIG_H

//===================================================================
// Includes & Setup
//===================================================================
#include <Arduino.h>
#include <Bounce.h> 
#include <Audio.h> 
#include <Wire.h> 
#include <SPI.h> 
#include <SD.h>   // or #include <SdFat.h> if you prefer
//#include <SdFat.h>
#include <MIDI.h> 
//#include <usb_midi.h>
#include <SerialFlash.h> 
#include <ResponsiveAnalogRead.h> 
#include <RTClib.h> // if you want RTC usage

// Then your pin definitions, constants, etc.
#include "core_pins.h" // if your original code used it, or anything else

// ------------------------------------------------------
// Optional RTC
// ------------------------------------------------------
#define PLACE_MARKER_PIN 9

// ------------------------------------------------------
// MIDI Macros
// ------------------------------------------------------
#define NOTE_OFF_EVENT          0x80
#define NOTE_ON_EVENT           0x90
#define CONTROL_CHANGE_EVENT    0xB0
#define PITCH_BEND_EVENT        0xE0
#define AFTER_TOUCH_POLY_EVENT  0xA0
#define RECORDING_TIMEOUT       120000
#define FILE_FLUSH_INTERVAL     400

//===================================================================
// WAV Browsing + Final Mixer
//===================================================================
#define sampleBrowsePin 24 // direct match to snippet

//=================================================================== 
// Additional Looper / Recording / MIDI 
//=================================================================== 
#define MAX_TRACKS 4 
#define MAX_NOTES 500 
#define MAX_SEQUENCES 4
#define DISABLE_THRU 
#define METRONOME_NOTE 64 
#define METRONOME_CHANNEL 10 
// #define SEND_INT_CLOCK 
// #define EXT_CLOCK 
const byte RECPin = 32; 
const byte startPin = 25; 
const byte clockTrigPin = 27; 
const byte pushRotaryPin= 16; 
const byte undoPin = 31; 
const byte trackPin[MAX_TRACKS] = {28,29,3,2}; 
const byte optAPin = 34; 
const byte optBPin = 33; 
const byte RECLEDPin = 36; 
const byte PLAYledPin = 37; 
const byte trackLEDPin[MAX_TRACKS] = {15,17,5,4}; 


// ... the rest of your #defines, pin mappings, etc.

#endif // CONFIG_H

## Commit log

2024-03-25 Create Schematics
2024-04-13 README-STLs.md
    Specifies 3D printing filament used for each part
2024-05-21 Added KiCad WDM(RevB_1) project files
    [WDM(RevB_V1).kicad_pcb]
2024-05-21 Updated PCB zones & board outline. Also uploaded revised pin definitions to match routing
    [WDM(RevB_V1).kicad_pcb]
2024-05-21 Added symbol and footprint libraries to KiCad files
2024-05-21 Added 3D models to Kicad files
2024-05-26 Added Gerber & Drill files
2025-01-17 Delete Version 2/Hardware/MCAD Files/Bottom_Enclosure_WDM(RevB)_4.3.STL
    Renamed for clarity and reuploaded.
    [Bottom_Enclosure_WDM(RevB)_4.3.STL]
2025-01-17 Delete Version 2/Hardware/MCAD Files/ButtonActuators_WDM(RevB)_4.3.STL
    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
    [ButtonActuators_WDM(RevB)_4.3.STL]
2025-01-17 Delete Version 2/Hardware/MCAD Files/Top_Enclosure_WDM(RevB)_4.3.STL
    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
    [Top_Enclosure_WDM(RevB)_4.3.STL]
2025-03-07 Add files via upload
    - Modularized the monolith from version 1
    - Added flash logic for handling alternative samples
